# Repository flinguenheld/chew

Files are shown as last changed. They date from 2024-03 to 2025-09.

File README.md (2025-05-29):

Chew both (https://live.staticflickr.com/65535/54516924634_889acfa799_o.jpg)  
A crunched 34 key choc-spaced keyboard.

&nbsp;

---

# Split

<div align="center">
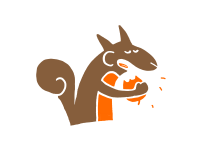
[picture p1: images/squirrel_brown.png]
  
</div>

Chew split (https://live.staticflickr.com/65535/54515879542_4f3b09451c_o.jpg)  
The original.

### Requirements

- 2x PCB
- 2x MCU board [0xCB Gemini](https://github.com/0xCB-dev/0xCB-Gemini) or [RP2040-Zéro](https://www.waveshare.com/wiki/RP2040-Zero)
- 2x TRRS jack
- 34x switches Choc V1 **only**
- 34x keycaps Choc V1

Optional:
- 23x [Mill Max sockets](https://splitkb.com/collections/keyboard-parts/products/mill-max-low-profile-sockets)
- 34x [Kailh hotswap sockets](https://cdn.shopify.com/s/files/1/0588/1108/9090/files/5118-Choc-Socket.pdf?v=1686715063)
- 2x [Piezo buzzer](https://keeb.supply/products/piezo-buzzer)
- 2x Back PCB + screws and bolts
- 2x [Tenting pucks](https://splitkb.com/collections/keyboard-parts/products/tenting-puck)
- 2x [Tripods](https://www.manfrotto.com/us-en/pocket-support-large-black-mp3-bk/)

### Test

You can print these templates to test if it fits your hands:  
- [Left](./images/shape_left.pdf)
- [Right](./images/shape_right.pdf)

### Firmware

Chew is now running with it's [custom firmware](https://github.com/flinguenheld/rusty_chew) written in rust ! 🦀  

It also runs on [QMK](https://docs.qmk.fm/#/),  you can see it's [folder](https://github.com/qmk/qmk_firmware/tree/master/keyboards/chew/split) and my [keymap](https://github.com/flinguenheld/qmk_chew).

### How to build

Check the [wiki](https://github.com/flinguenheld/chew/wiki).

### Brainwave

Chew is a mix of these two cool keyboards:  

[Ferris sweep](https://github.com/davidphilipbarr/Sweep)  
[Wubbo](https://github.com/cacheworks/Wubbo)

&nbsp;

Chew split (https://live.staticflickr.com/65535/54515879552_5bc9421ecd_o.jpg)  

<div align="center" style="margin: 30px;">
  
</div>

---

# Mono

<div align="center">
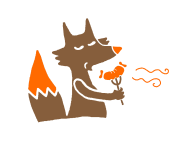
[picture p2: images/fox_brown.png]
  
</div>

Chew mono (https://live.staticflickr.com/65535/54517001878_02305ed23b_o.jpg)  
The same, monobloc though !

### Requirements

- 1x PCB
- 1x MCU board [0xCB Gemini](https://github.com/0xCB-dev/0xCB-Gemini) or [RP2040-Zéro](https://www.waveshare.com/wiki/RP2040-Zero)
- 34x [1N4148W SMD diodes](https://splitkb.com/collections/keyboard-parts/products/smd-diodes)
- 34x switches Choc V1 **only**
- 34x keycaps Choc V1

Optional:
- 18x [Mill Max sockets](https://splitkb.com/collections/keyboard-parts/products/mill-max-low-profile-sockets)
- 34x [Kailh hotswap sockets](https://cdn.shopify.com/s/files/1/0588/1108/9090/files/5118-Choc-Socket.pdf?v=1686715063)  
- 1x [Piezo buzzer](https://keeb.supply/products/piezo-buzzer)
- 1x Back PCB + screws and bolts

### Test

You can print this [template](./images/shape_mono.pdf) to test if it fits your hands.

### Firmware

The [rusty firmware](https://github.com/flinguenheld/rusty_chew) also works with this version. 🦀  

Or its [QMK folder](https://github.com/qmk/qmk_firmware/tree/master/keyboards/chew/mono) with my [keymap](https://github.com/flinguenheld/qmk_chew).  

### How to build

Check the [wiki](https://github.com/flinguenheld/chew/wiki).

&nbsp;

Chew mono (https://live.staticflickr.com/65535/54517001868_2b600309fd_o.jpg)  

<div align="center" style="margin: 30px;">
  
</div>

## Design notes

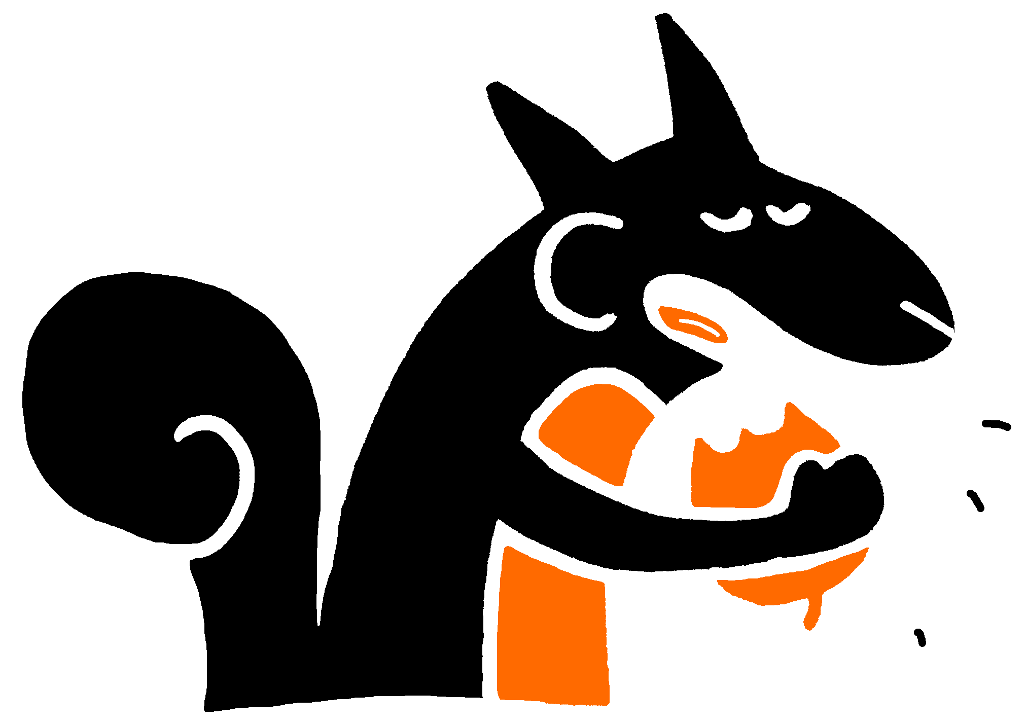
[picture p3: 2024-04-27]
images/squirrel.png

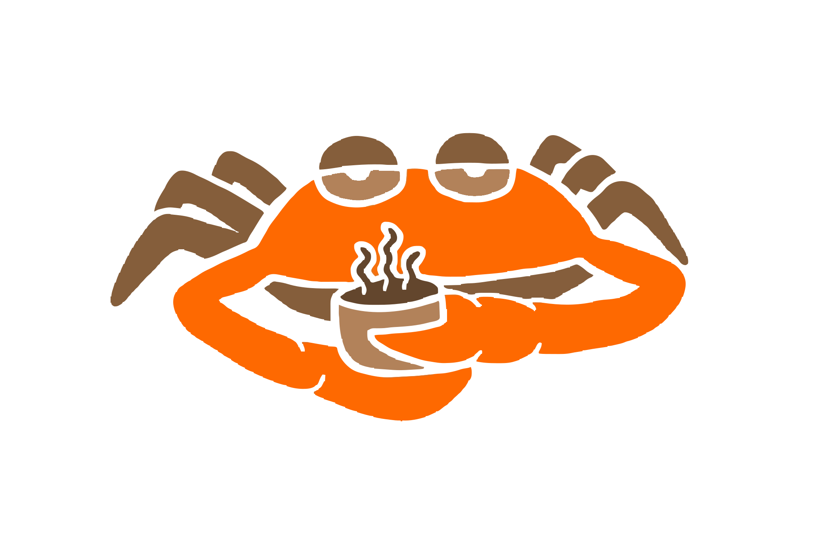
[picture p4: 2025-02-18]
images/crab_coffee_large.png

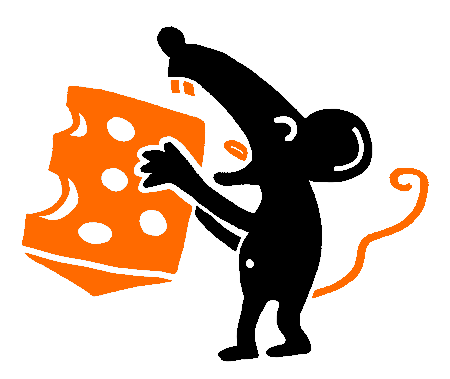
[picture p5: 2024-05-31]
images/mouse.png

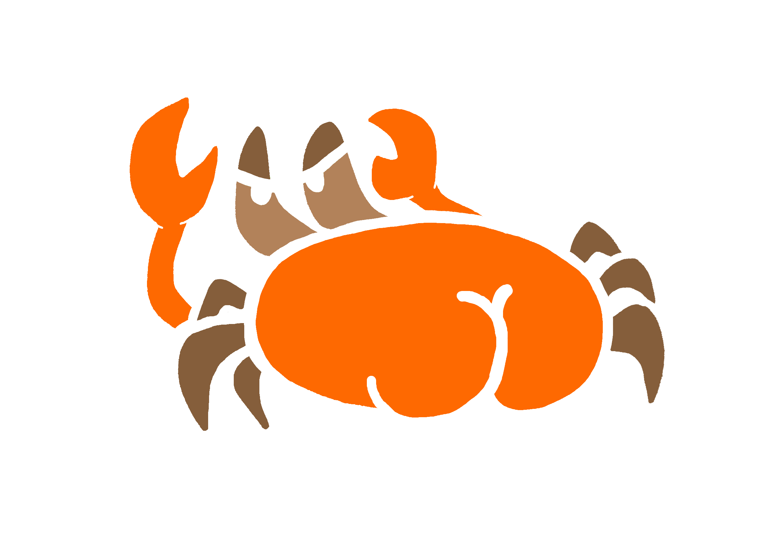
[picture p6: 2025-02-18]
images/crab_angry_large.png

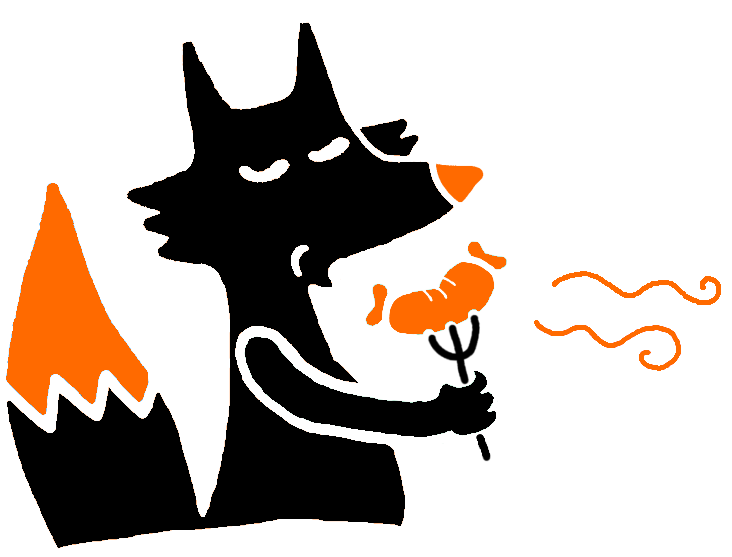
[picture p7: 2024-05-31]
images/fox.png

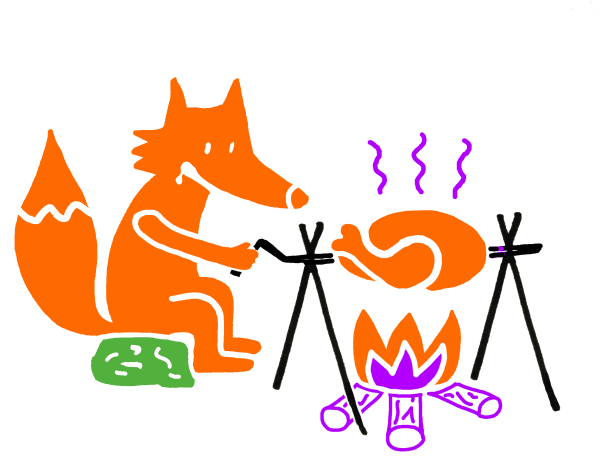
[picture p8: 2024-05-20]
images/firefox.png

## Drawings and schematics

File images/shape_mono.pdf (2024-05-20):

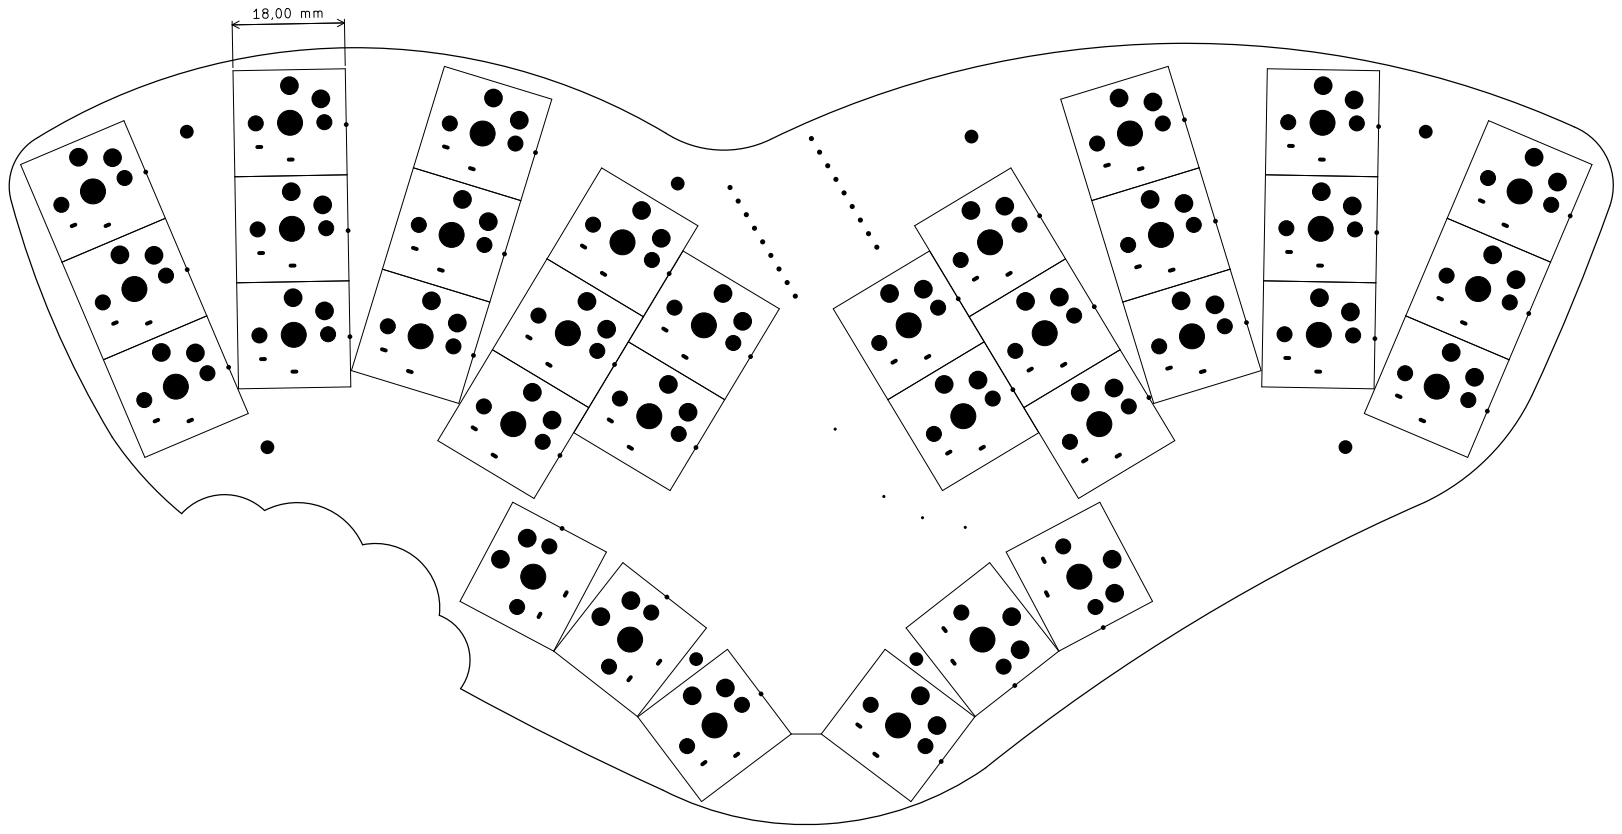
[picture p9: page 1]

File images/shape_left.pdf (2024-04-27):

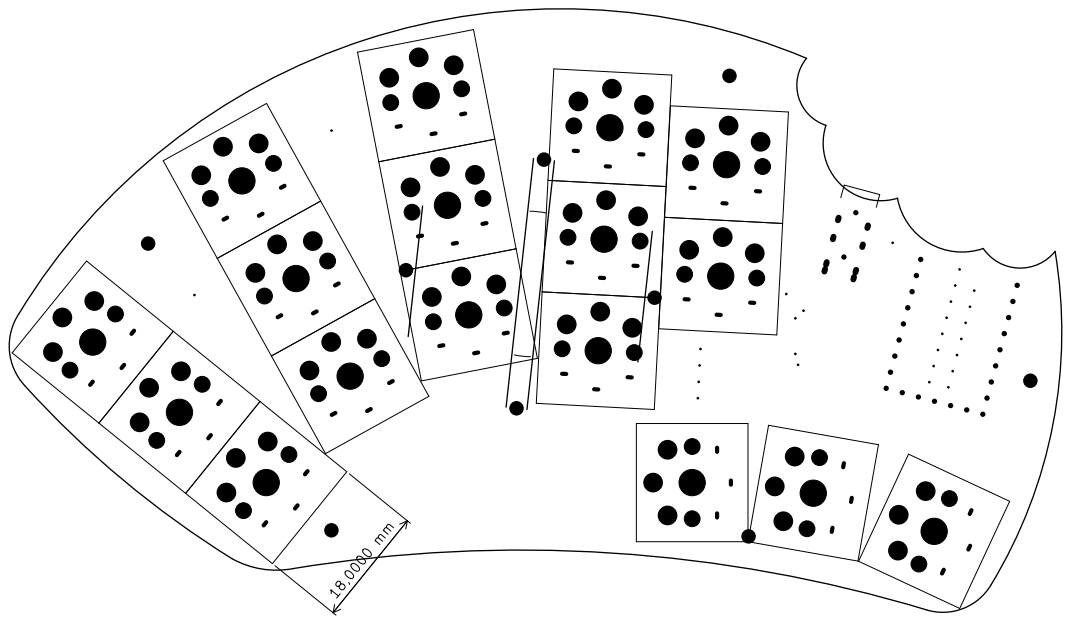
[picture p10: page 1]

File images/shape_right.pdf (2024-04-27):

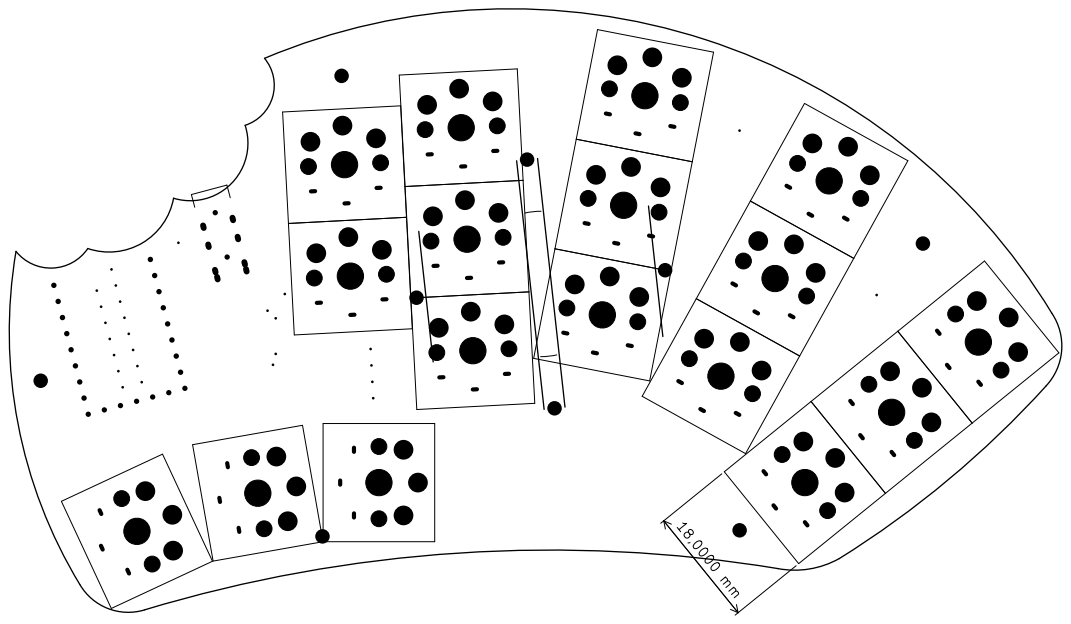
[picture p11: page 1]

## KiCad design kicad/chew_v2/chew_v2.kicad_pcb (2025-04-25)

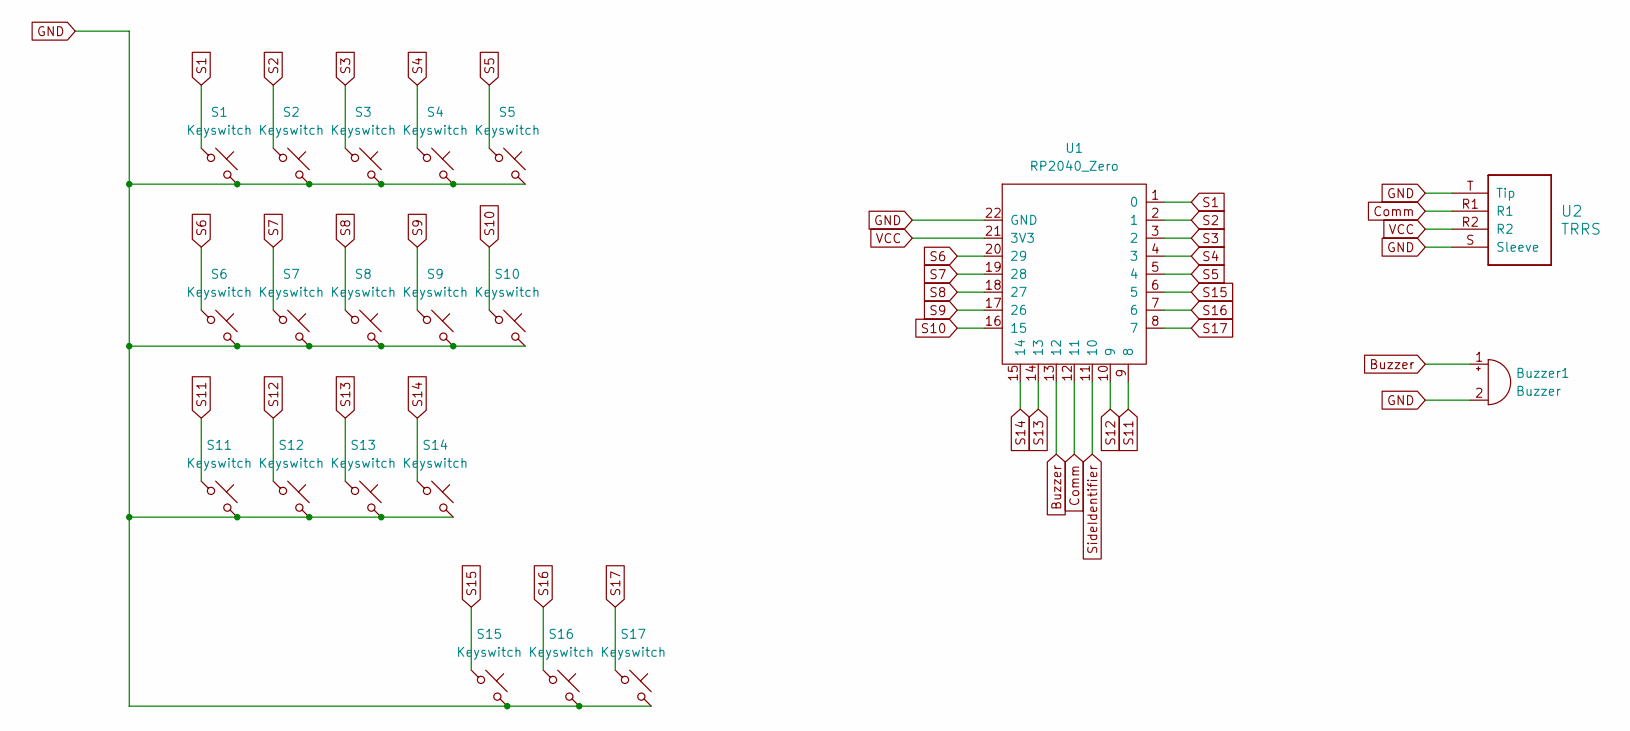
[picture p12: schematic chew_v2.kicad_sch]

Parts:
Buzzer1: Buzzer; Buzzer_Mallory_AST1109MLTRQ
S1, S3, S5, S7, S8, S9, S11, S12, S14, S16, S17: Keyswitch; Choc_V1_chew_reversible_1
S2, S4, S6, S10, S13, S15: Keyswitch; Choc_V1_chew_reversible_2
U1: RP2040_Zero; RP2040_Zero_chew_reversible
U2: TRRS; TRRS_chew_reversible

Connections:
Buzzer: Buzzer1.1 (+), U1.13 (12)
Comm: U1.12 (11), U2.R1
GND: Buzzer1.2 (-), S1.2, S2.2, S3.2, S4.2, S5.2, S6.2, S7.2, S8.2, S9.2, S10.2, S11.2, S12.2, S13.2, S14.2, S15.2, S16.2, S17.2, U1.22 (GND), U2.S (Sleeve), U2.T (Tip)
S1: S1.1, U1.1 (0)
S2: S2.1, U1.2 (1)
S3: S3.1, U1.3 (2)
S4: S4.1, U1.4 (3)
S5: S5.1, U1.5 (4)
S6: S6.1, U1.20 (29)
S7: S7.1, U1.19 (28)
S8: S8.1, U1.18 (27)
S9: S9.1, U1.17 (26)
S10: S10.1, U1.16 (15)
S11: S11.1, U1.9 (8)
S12: S12.1, U1.10 (9)
S13: S13.1, U1.14 (13)
S14: S14.1, U1.15 (14)
S15: S15.1, U1.6 (5)
S16: S16.1, U1.7 (6)
S17: S17.1, U1.8 (7)
SideIdentifier: U1.11 (10)
VCC: U1.21 (3V3), U2.R2

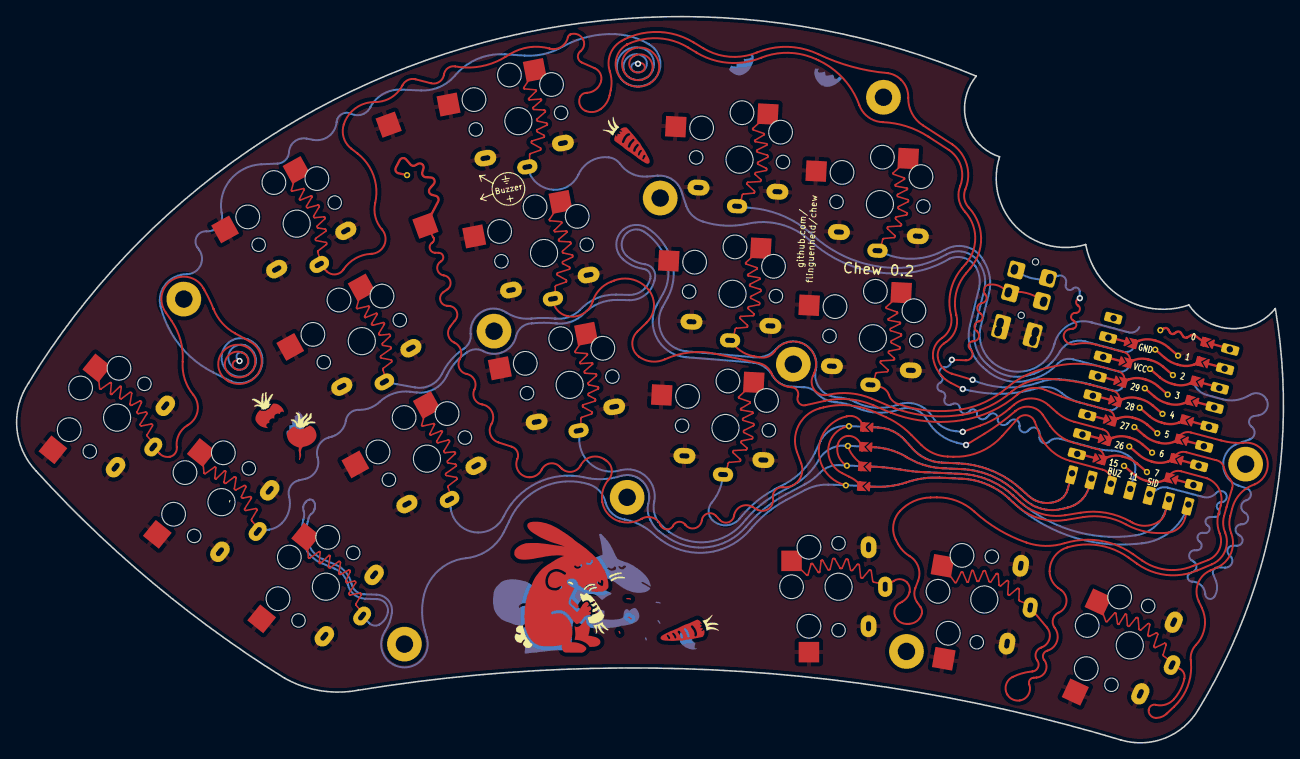
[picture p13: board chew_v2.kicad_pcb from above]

Board: 2 copper layers, 160.3 x 91.9 mm, 20 parts (0 on the bottom side), 21 nets.

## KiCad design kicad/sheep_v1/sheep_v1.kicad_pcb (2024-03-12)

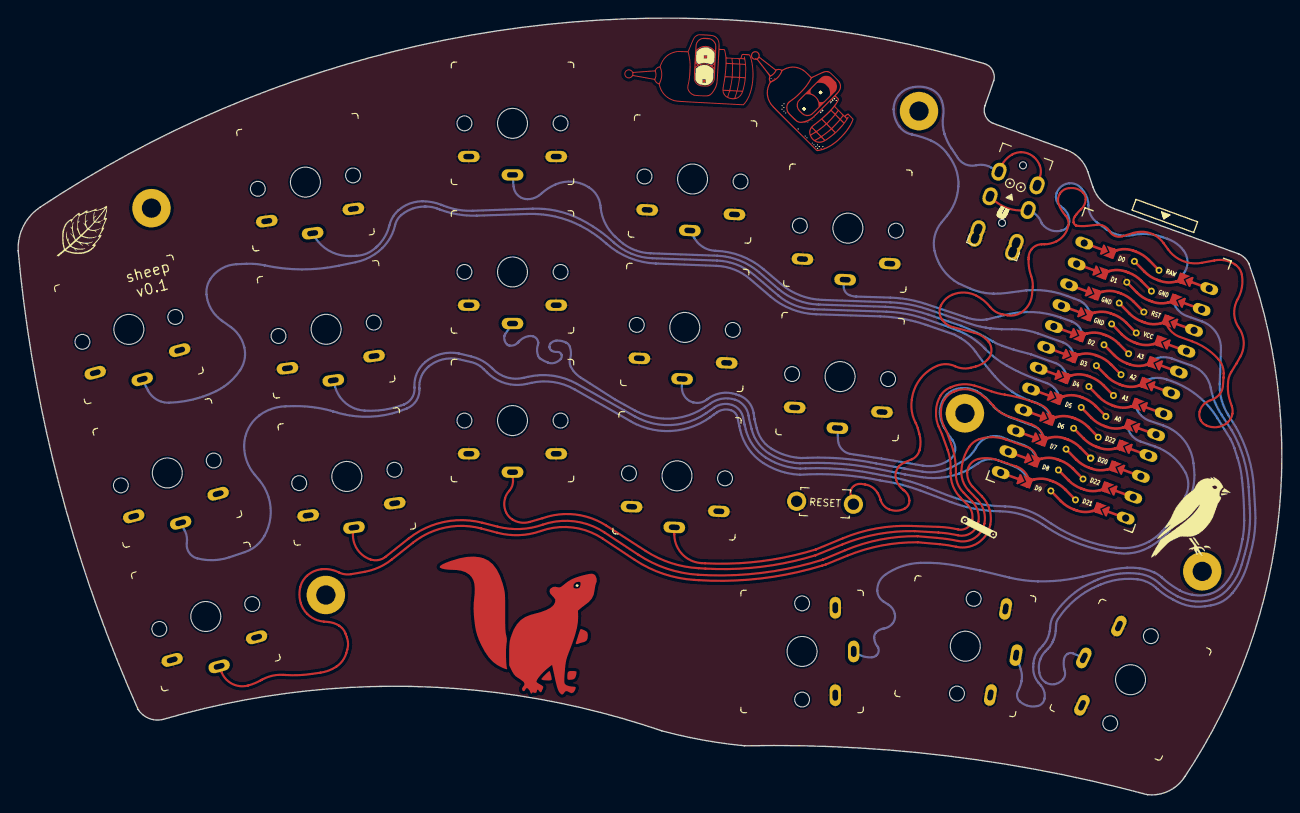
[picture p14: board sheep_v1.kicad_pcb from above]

Board: 2 copper layers, 144.6 x 88.9 mm, 20 parts (0 on the bottom side), 21 nets.

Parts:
J2: AudioJack4dpb; TRRS-PJ-DPB2
RSW2: SW_PUSH; ResetSW_1side
SW1, SW2, SW3, SW4, SW5, SW6, SW7, SW8, SW9, SW10, SW11, SW12, SW13, SW14, SW15, SW16, SW17: SW_Push; SW_PG1350_rev_DPB
U1: ProMicro-kbd; ProMicro_jumpers_facedown

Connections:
Switch1: SW1.1, U1.20
Switch2: SW2.1, U1.19
Switch3: SW3.1, U1.18
Switch4: SW4.1, U1.17
Switch5: SW5.1, U1.16
Switch6: SW6.1, U1.15
Switch7: SW7.1, U1.14
Switch8: SW8.1, U1.13
Switch9: SW9.1, U1.8
Switch10: SW10.1, U1.7
Switch11: SW11.1, U1.9
Switch12: SW12.1, U1.10
Switch13: SW13.1, U1.11
Switch14: SW14.1, U1.12
Switch15: SW15.1, U1.2
Switch16: SW16.1, U1.5
Switch17: SW17.1, U1.6
Switch18: J2.R1, U1.1
gnd: J2.S, J2.T, RSW2.2, SW1.2, SW2.2, SW3.2, SW4.2, SW5.2, SW6.2, SW7.2, SW8.2, SW9.2, SW10.2, SW11.2, SW12.2, SW13.2, SW14.2, SW15.2, SW16.2, SW17.2, U1.3, U1.4, U1.23
reset: RSW2.1, U1.22
vcc: J2.R2, U1.21

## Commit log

2024-03-04 Init & place switchs
    [pouet.kicad_pcb, pouet.kicad_sch]
2024-03-05 Shape ok
    [base_ok.kicad_pcb, base_ok.kicad_sch, no6thcolumn.kicad_pcb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]
2024-03-05 Set map
    [routes.kicad_pcb, routes.kicad_sch]
2024-03-05 Routes ok
    [routes-B_Cu.gbr, routes-B_Mask.gbr, routes-B_Paste.gbr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]
2024-03-06 More curves
    [base_ok.kicad_pcb, base_ok.kicad_sch, no6thcolumn.kicad_pcb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]
2024-03-09 Add qmk files
    [routes.kicad_pcb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]
2024-03-10 Test reversed controller
    [sheep_v1-B_Cu.gbr, sheep_v1-B_Mask.gbr, sheep_v1-B_Silkscreen.gbr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]
2024-03-11 Reversed controller ok + up matrix pins
    [sheep_v1.kicad_pcb, sheep_v1.kicad_sch, test_reverse_controller.kicad_pcb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]
2024-03-12 Reverse pads & up mergins
    [sheep_v1-B_Cu.gbr, sheep_v1-B_Mask.gbr, sheep_v1-B_Paste.gbr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]
2024-03-15 Add art
    [sheep_plate.kicad_pcb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]
2024-03-15 Rename to chew
    [chew_v1-B_Cu.gbr, chew_v1-B_Mask.gbr, chew_v1-B_Paste.gbr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]
2024-03-15 Move that rabbit
    [chew_v1-B_Cu.gbr, chew_v1-B_Mask.gbr, chew_v1-B_Paste.gbr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]
2024-03-16 Add tenting puck
    [chew_v1-B_Cu.gbr, chew_v1-B_Mask.gbr, chew_v1-B_Paste.gbr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]
2024-03-18 Add backplate & art
    [chew_v1-B_Cu.gbr, chew_v1-B_Mask.gbr, chew_v1-B_Paste.gbr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]
2024-03-28 Enlarge pads
    [chew_v1-B_Cu.gbr, chew_v1-B_Mask.gbr, chew_v1-B_Paste.gbr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]
2024-03-29 Up backplate + add tenting hole version
    [chew_v1_backplate-B_Cu.gbr, chew_v1_backplate-B_Mask.gbr, chew_v1_backplate-B_Paste.gbr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]
2024-04-02 Add hotswap option
    [chew_v1-B_Cu.gbr, chew_v1-B_Mask.gbr, chew_v1-B_Paste.gbr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]
2024-04-03 Up column angles + edges
    [chew_v1.kicad_pcb, chew_v1.kicad_sch]
2024-04-04 Up backplates
    [chew_v1_backplate.kicad_pcb, chew_v1_backplate_tenting.kicad_pcb, chew_v1_backplate_tenting_hole.kicad_pcb]
2024-04-15 Add RP2040 zero
    [chew_v1_zero.kicad_pcb, chew_v1_zero_up_angle.kicad_pcb]
2024-04-16 Add routes
    [chew_v1_zero.kicad_pcb, chew_v1_zero_up_angle.kicad_pcb]
2024-04-17 Add backplate
    [chew_v1_zero.kicad_pcb]
2024-04-21 Rename to chew zero
    [chew_v1_backplate.kicad_pcb, chew_v1_backplate_tenting.kicad_pcb, chew_v1_zero.kicad_pcb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]
2024-04-27 Add images
    [chew_v1_backplate.kicad_pcb, chew_v1_backplate_tenting.kicad_pcb, chew_v1_zero.kicad_pcb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]
2024-04-30 QMK PR ok 🚀
2024-04-30 Add VBus
    [chew_zero_v1_vbus.kicad_pcb]
2024-05-01 Set VBus by default
    [chew_v1.kicad_pcb, chew_zero_v1.kicad_pcb, chew_zero_v1.kicad_sch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]
2024-05-01 Up silkscreen
    [chew_v1.kicad_pcb]
2024-05-10 Create mono schematics
    [mono_v1.kicad_pcb, mono_v1.kicad_sch]
2024-05-12 Add mono traces
    [chew_v1.kicad_pcb]
2024-05-13 Create libs
    [chew_v1.kicad_pcb, chew_v1.kicad_sch]
2024-05-13 Replace footprints
    [chew_v1.kicad_pcb, chew_v1.kicad_sch]
2024-05-13 Mono shape ok
    [mono_v1.kicad_sch]
2024-05-20 Mono prod
    [chew_v1.kicad_pcb, mono_v1.kicad_sch, mono_v1_backplate.kicad_pcb]
2024-05-22 Simplify switch traces
    [chew_v1.kicad_pcb, mono_v1.kicad_sch]
2025-02-20 Add rusty backplate
    [chew_v1_backplate.kicad_pcb, chew_v1_backplate_rusty.kicad_pcb, chew_v1_backplate_tenting.kicad_pcb]
2025-04-25 Add buzzer & clean silkscreen
    [chew_v1.kicad_pcb, chew_v1.kicad_sch, chew_v1_backplate.kicad_pcb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]
2025-09-05 Up backplates with buzzer holes
    [chew_v2_backplate.kicad_pcb, mono_v2_backplate.kicad_pcb]
